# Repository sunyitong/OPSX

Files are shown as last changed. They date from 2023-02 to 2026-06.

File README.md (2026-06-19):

# OPSX-SX70

[中文](README.zh-CN.md) | English






OPSX-SX70 is an open-source replacement core board for the **Polaroid SX-70** instant camera, built around the Raspberry Pi RP2040. It provides a hackable, repair-friendly electronics platform while preserving the essential camera-control behavior of the original board.

## Highlights

- RP2040-based camera control board.
- Factory-ready Gerber files.
- Interactive HTML bill of materials.
- Schematic PDF for circuit inspection.
- MicroPython firmware for rapid iteration.
- Rust firmware workspace reserved for future high-performance control code.

## Repository Layout

| Path | Contents |
| --- | --- |
| [`bom/`](bom/) | Interactive HTML bill of materials for component lookup and placement. |
| [`code/micropython/`](code/micropython/) | Current firmware implementation for the RP2040 board. |
| [`code/rust/`](code/rust/) | Placeholder for future Rust firmware. |
| [`gerber/`](gerber/) | PCB production files and SMT position CSV. |
| [`schematic/`](schematic/) | One-page schematic PDF. |
| [`docs/`](docs/) | Fabrication, firmware, calibration, and safety notes. |

## Hardware

OPSX targets a thin two-layer PCB suitable for the physical constraints of the SX-70 body.

Recommended fabrication settings:

- **Layers:** 2 copper layers
- **PCB thickness:** 0.8 mm or less
- **Assembly:** review the interactive BOM before ordering or hand assembly
- **Files:** use the Gerber package under [`gerber/`](gerber/)

Read [`docs/fabrication.md`](docs/fabrication.md) before manufacturing.

## Firmware

The current firmware is written in MicroPython and lives in [`code/micropython/`](code/micropython/).

Core modules:

- `main.py`: camera-control loop, shutter/motor logic, exposure modes, distance display, and sensor integration.
- `ssd1306.py`: OLED display driver.
- `vl53l1x.py`: time-of-flight distance sensor driver.

Read [`docs/firmware.md`](docs/firmware.md) before flashing the board.

## Calibration and Safety

OPSX controls camera electromechanical parts including a shutter solenoid and motor. Incorrect calibration can damage the camera or board.

Before first use:

1. Read [`docs/safety.md`](docs/safety.md).
2. Inspect soldering and continuity.
3. Calibrate `SOLENOID_THRESHOLD` in `main.py`.
4. Test motor and sensor behavior outside the camera body where possible.
5. Reassemble only after confirming stable control behavior.

## Useful References

- Interactive BOM: [`bom/OPSX_bom.html`](bom/OPSX_bom.html)
- Schematic: [`schematic/OPSX_schematic.pdf`](schematic/OPSX_schematic.pdf)
- Gerbers: [`gerber/`](gerber/)
- KiCad source request: [issue #2](https://github.com/sunyitong/OPSX-SX70/issues/2)
- Latest release: <https://github.com/sunyitong/OPSX-SX70/releases/latest>
- SX-70 repair reference: <https://instantphotography.files.wordpress.com/2010/12/polaroid-sx-70-camera-repair-book.pdf>

## Roadmap

- Document complete assembly photographs.
- Package Gerber/BOM/schematic as GitHub Releases.
- Add firmware upload scripts.
- Add Rust firmware implementation.
- Add calibration logs for different SX-70 bodies.

## Author

Created by [Yitong Sun](https://github.com/sunyitong), a researcher and developer working across computational design, sensing systems, XR, and open hardware.

- Website: <https://www.yitongsun.com>
- Email: <hi@yitongsun.com>

## License

This project is released under the [GNU General Public License v3.0](LICENSE). Any distribution or modification based on this project should clearly attribute the source.

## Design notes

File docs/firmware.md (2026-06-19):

# Firmware Guide

The current OPSX firmware is implemented in MicroPython for RP2040.

## Files

- `code/micropython/main.py`: control logic and camera behavior
- `code/micropython/ssd1306.py`: OLED display driver
- `code/micropython/vl53l1x.py`: time-of-flight sensor driver

## Flashing Workflow

1. Install a MicroPython RP2040 firmware image on the board.
2. Copy the files in `code/micropython/` to the board filesystem.
3. Power-cycle the board.
4. Observe OLED output and sensor readings.
5. Calibrate `SOLENOID_THRESHOLD` before actuating the shutter inside a camera body.

## Important Constant

`SOLENOID_THRESHOLD` in `main.py` controls the hold duty cycle for the shutter solenoid. It should be tuned through self-test and should not be treated as universal across boards or camera bodies.

## Future Work

The `code/rust/` directory is reserved for a future Rust firmware implementation.

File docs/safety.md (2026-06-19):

# Safety Notes

OPSX is an experimental open-hardware project for camera repair, research, and modification.

## Mechanical Risk

The Polaroid SX-70 contains delicate mechanical assemblies. Disassembly and board replacement require care, patience, and appropriate tools.

Read the SX-70 repair reference before disassembly:

<https://instantphotography.files.wordpress.com/2010/12/polaroid-sx-70-camera-repair-book.pdf>

## Electrical Risk

- Inspect solder joints before applying power.
- Check for shorts on power rails.
- Do not actuate solenoids or motors without calibration.
- Watch for overheating during early tests.
- Disconnect power before reworking the board.

## Firmware Risk

Incorrect shutter or motor timings can damage mechanical parts. Calibrate gradually and document working values for each camera body.

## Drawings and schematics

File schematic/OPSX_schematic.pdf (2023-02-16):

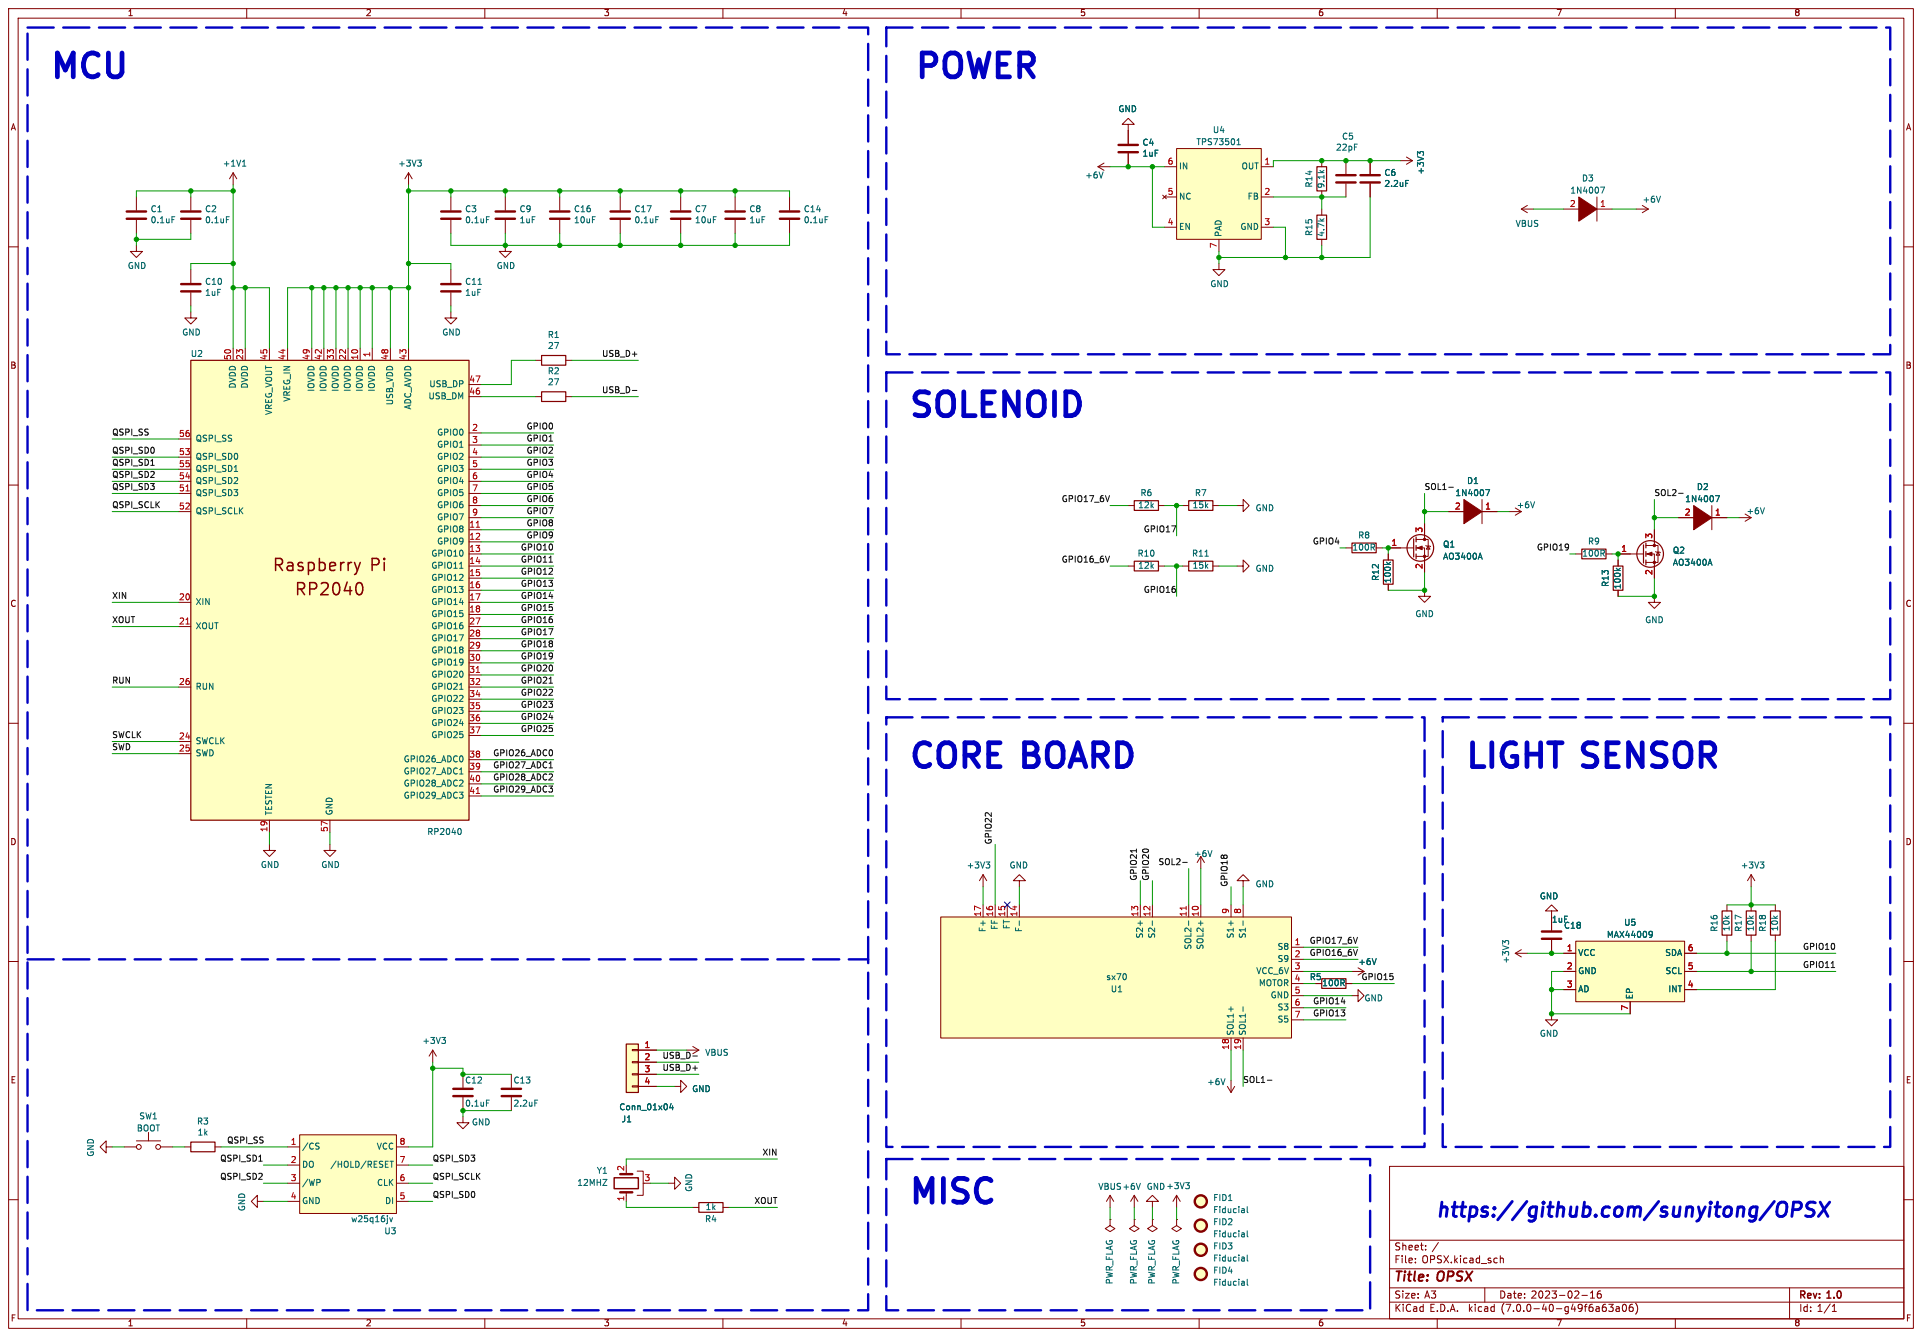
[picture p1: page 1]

1 IOVDD 10 GPIO8 11 GPIO9 12 GPIO10 13 GPIO11 14 GPIO12 15 GPIO13 16 GPIO14 17 GPIO15 18 TESTEN 19 GPIO0 2 XIN 20 XOUT 21 IOVDD 22 DVDD 23 SWCLK 24 SWD 25 RUN 26 GPIO16 27 GPIO17 28 GPIO18 29 GPIO1 3 GPIO19 30 GPIO20 31 GPIO21 32 IOVDD 33 GPIO22 34 GPIO23 35 GPIO24 36 GPIO25 37 GPIO26_ADC0 38 GPIO27_ADC1 39 GPIO2 4 GPIO28_ADC2 40 GPIO29_ADC3 41 IOVDD 42 ADC_AVDD 43 VREG_IN 44 VREG_VOUT 45 USB_DM 46 USB_DP 47 USB_VDD 48 IOVDD 49 GPIO3 5 DVDD 50 QSPI_SD3 51 QSPI_SCLK 52 QSPI_SD0 53 QSPI_SD2 54 QSPI_SD1 55 QSPI_SS 56 GND 57 GPIO4 6 GPIO5 7 GPIO6 8 GPIO7 9 U2 RP2040 GND

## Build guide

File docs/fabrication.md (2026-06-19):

# Fabrication Guide

OPSX is designed for the physical constraints of the Polaroid SX-70 body.

## Recommended PCB Settings

- 2 copper layers
- 0.8 mm thickness or less
- Standard solder mask
- Review edge cuts before ordering
- Review the SMT position CSV if using assembly service

## Production Files

Use the files under `gerber/`:

- copper: `OPSX-F_Cu.gbr`, `OPSX-B_Cu.gbr`
- solder mask: `OPSX-F_Mask.gbr`, `OPSX-B_Mask.gbr`
- paste: `OPSX-F_Paste.gbr`, `OPSX-B_Paste.gbr`
- silkscreen: `OPSX-F_Silkscreen.gbr`, `OPSX-B_Silkscreen.gbr`
- drills: `OPSX-PTH.drl`, `OPSX-NPTH.drl`
- board outline: `OPSX-Edge_Cuts.gbr`
- SMT placement: `OPSX-pos.csv`

## Pre-Order Checklist

- Confirm board thickness with the manufacturer.
- Open the Gerbers in an independent viewer.
- Check connector orientation and board outline.
- Review the interactive BOM in `bom/OPSX_bom.html`.
- Confirm that every component is available or has a tested substitute.

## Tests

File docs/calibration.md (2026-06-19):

# Calibration Notes

OPSX interacts with electromechanical parts whose behavior can vary across camera bodies. Treat the default values as a starting point, not as guaranteed production settings.

## Solenoid Threshold

`SOLENOID_THRESHOLD` is used to hold the shutter solenoid after the initial actuation pulse.

Recommended process:

1. Start with conservative values.
2. Test actuation outside the camera body if possible.
3. Check heat, current draw, and mechanical response.
4. Increase only when the shutter does not hold reliably.
5. Record the working value for the specific board and camera.

## Sensor Checks

- Confirm I2C communication before triggering mechanical actions.
- Confirm distance readings from the VL53L1X sensor.
- Confirm OLED output before final assembly.

## Exposure Modes

The MicroPython firmware contains exposure constants such as `ev7`, `ev8`, and `ev16`. If changing exposure behavior, document the mapping and test with real film only after bench verification.

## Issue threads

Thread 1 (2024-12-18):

控制板的文件

Armsinrius, 2024-12-18:
尊敬的Sun先生,
偶然看见您的开源项目OPSX，我个人觉得非常有意思．您在２０２３年２月１６日在小红书评论提到，将会修改控制器的部分方案后上传Github，然而我并未在此项目或您其他公开的项目中找到控制器的相关文件．如若允许，是否可以请求您上传控制器的方案．非常感谢您的工作给广大宝丽来爱好者带来的喜悦与便利．也非常感谢您无私的开源．
谨致问候

sunyitong, 2025-01-25:
你好，因为后来经过测试发现不同时期不同型号的SX-70机型的闪光灯插口的内置IC不同，所以目前的控制板并不能通用，如果需要通用则需要拆开机头将原装IC取出并替换一个柔性电路板进去。改造难度相对比较高，所以一直没有发布。

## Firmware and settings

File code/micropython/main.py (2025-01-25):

from machine import Pin, I2C, PWM
import time
from ssd1306 import SSD1306_I2C
from vl53l1x import VL53L1X
import framebuf

# Caution! This value is used to hold the shutter solenoid and should be modified by self-test.
SOLENOID_THRESHOLD = 20000


def shut(apture, f="1"):
    sht.duty_u16(65535)
    time.sleep_ms(18)
    sht.duty_u16(SOLENOID_THRESHOLD) 
    motor.value(1)
    while True:
        if s3.value() == 1:
            motor.value(0)
            break

    sht.duty_u16(0)
    if f == '0':
        gap=int(apture*0.3)
        time.sleep_ms(gap)
        fl.value(1)
        time.sleep_ms(gap)
        fl.value(0)
        time.sleep_ms(gap)
    elif f == '1':
        time.sleep_ms(apture)
    elif f == 'B':
        time.sleep_ms(15)
        while True:
            time.sleep_ms(3)
            if btn.value() == 1:
                break
    elif f == 'T':
        time.sleep(100)
        while True:
            time.sleep(3)
            if btn.value() == 0:
                break
        
    sht.duty_u16(65535)
    time.sleep_ms(20)
    sht.duty_u16(SOLENOID_THRESHOLD)
    motor.value(1)
    while True:
        if s5.value() == 0:
            motor.value(0)
            sht.duty_u16(0)
            break

def plug():
    a = plugI2c.readfrom_mem(32, 0x00, 2)
    one = "%8d" %int(bin(a[0])[2:])
    two = "%8d" %int(bin(a[1])[2:])
    one = one.replace(" ","0")
    return one+two

def showFrame():
    display.fill(0)
    display.fill_rect(0, 0, 128, 11, 1)
    display.vline(51, 0, 11, 0)
    display.vline(82, 0, 11, 0)
    
def backFunc():
    showFrame()
    fullp = plug()
    ec = fullp[2:6]
    sw = fullp[0:2]
    encoder()
    switch()
    dist()
    display.show()

# iso=1 for 600 paper =0 for 70 paper
def lux(iso=1):
    h = i2c.readfrom_mem(74, 0x03, 1)
    l = i2c.readfrom_mem(74, 0x04, 1)
    luxb = bin(((h[0] << 4) | l[0]) | 4096)
    expo = 8*int(luxb[3]) + 4*int(luxb[4]) + 2*int(luxb[5]) + int(luxb[6])
    manti = 128*int(luxb[7]) + 64*int(luxb[8]) + 32*int(luxb[9]) + 16*int(luxb[10]) + 8*int(luxb[11]) + 4*int(luxb[12]) + 2*int(luxb[13]) + int(luxb[14])
    lux = 2**expo * manti * 0.045
    if iso == 0:
        if 2.5<lux<=3.52:
            return ev75
        elif 3.52<lux<=4.99:
            return ev8
        elif 4.99<lux<=7.12:
            return ev85
        elif 7.12<lux<=10.13:
            return ev9
        elif 10.13<lux<=14.21:
            return ev95
        elif 14.21<lux<=19.79:
            return ev10
        elif 19.79<lux<=27.62:
            return ev105
        elif 27.62<lux<=39.01:
            return ev11
        elif 39.01<lux<=55.48:
            return ev115
        elif 55.48<lux<=78.07:
            return ev12
        elif 78.07<lux<=105.48:
            return ev125
        elif 105.48<lux<=150:
            return ev135
        elif 150<lux<=180:
            return ev145
        elif 180<lux<=200:
            return ev15
        elif 200<lux:
            return ev16
        else:
            return ev7
    else:
        if 0.3<lux<=0.5: 
            return ev75
        elif 0.5<lux<=0.9:
            return ev8
        elif 0.9<lux<=1.2:
            return ev85
        elif 1.2<lux<=1.74:
            return ev9
        elif 1.74<lux<=2.5:
            return ev95
        elif 2.5<lux<=3.52:
            return ev10
        elif 3.52<lux<=4.99:
            return ev105
        elif 4.99<lux<=7.12:
            return ev11
        elif 7.12<lux<=10.13:
            return ev115
        elif 10.13<lux<=14.21:
            return ev12
        elif 14.21<lux<=19.79:
            return ev125
        elif 19.79<lux<=27.62:
            return ev13
        elif 27.62<lux<=39.01:
            return ev135
        elif 39.01<lux<=55.48:
            return ev14
        elif 55.48<lux<=78.07:
            return ev145
        elif 78.07<lux<=105.48:
            return ev15
        elif 105.48<lux:
            return ev16
        else:
            return ev7

def encoder():
    if ec == EC_ZERO:
        display.text('AUTO', 10, 2, 0)
        return 'A'
    elif ec == EC_ONE:
        display.text('B', 23, 2, 0)
        return 'B'
    elif ec == EC_TWO:
        display.text('T', 23, 2, 0)
        return 'T'
    elif ec == EC_THREE:
        display.text('1/2', 15, 2, 0)
        return ev7
    elif ec == EC_FOUR:
        display.text('1/4', 15, 2, 0)
        return ev8
    elif ec == EC_FIVE:
        display.text('1/6', 15, 2, 0)
        return ev85
    elif ec == EC_SIX:
        display.text('1/8', 15, 2, 0)
        return ev9
    elif ec == EC_SEVEN:
        display.text('1/10', 10, 2, 0)
        return ev95
    elif ec == EC_EIGHT:
        display.text('1/15', 10, 2, 0)
        return ev10
    elif ec == EC_NINE:
        display.text('1/20', 10, 2, 0)
        return ev105
    elif ec == EC_A:
        display.text('1/30', 10, 2, 0)
        return ev11
    elif ec == EC_B:
        display.text('1/60', 10, 2, 0)
        return ev12
    elif ec == EC_C:
        display.text('1/125', 5, 2, 0)
        return ev13
    elif ec == EC_D:
        display.text('1/250', 5, 2, 0)
        return ev14
    elif ec == EC_E:
        display.text('1/500', 5, 2, 0)
        return ev15
    elif ec == EC_F:
        display.text('1/1000', 1, 2, 0)
        return ev16
    
def switch():
    if sw[0] == "1":
        display.text('600', 55, 2, 0)
    else:
        display.text('70', 59, 2, 0)
    if sw[1] == "1":
        display.text('OFF', 94, 2, 0)
    else:
        display.text('FLASH', 86, 2, 0)


def dist():
    display.text(str(round(tof.read()*0.001,2))+' m', 72, 23)

#基本定义
EC_ZERO = '1111'
EC_ONE = '0111'
EC_TWO = '1101'
EC_THREE = '0101'
EC_FOUR = '1110'
EC_FIVE = '0110'
EC_SIX = '1100'
EC_SEVEN = '0100'
EC_EIGHT = '1011'
EC_NINE = '0011'
EC_A = '1001'
EC_B = '0001'
EC_C = '1010'
EC_D = '0010'
EC_E = '1000'
EC_F = '0000'

ev7 = 600
ev75 = 440
ev8 = 280
ev85 =210
ev9 = 155
ev95 =120
ev10 = 97
ev105 = 70
ev11 = 48
ev115 = 40
ev12 = 33
ev125 = 29
ev13 = 25
ev135 = 23
ev14 = 21
ev145 = 20
ev15 = 19
ev16 = 18

back = "01"
front = "10"

#基本初始化
s8 = Pin(17, Pin.IN)
s9 = Pin(16, Pin.IN)
motor = Pin(15,Pin.OUT, value=0)
s3 = Pin(14, Pin.IN, Pin.PULL_UP)
s5 = Pin(13, Pin.IN, Pin.PULL_UP)
btn = Pin(18, Pin.IN, Pin.PULL_UP)
fl = Pin(22, Pin.OUT)
sht = PWM(Pin(4))
sht.freq(20000)
sht.duty_u16(0)
apt = Pin(19, Pin.OUT, value=0)
i2c = I2C(1, scl=Pin(11), sda=Pin(10))
plugI2c = I2C(0, scl=Pin(21), sda=Pin(20), freq=400000)
while True:
    plugscan = bool(plugI2c.scan())
    if plugscan == True:
        try:
            display = SSD1306_I2C(128, 32, plugI2c)
            display.contrast(0)
            tof = VL53L1X(plugI2c)
            fullp = plug()
            plugFlag = 1
            fb = fullp[6:8]
            func = "1"
            if fb == back:
                while True:
                    plugscan = bool(plugI2c.scan())
                    if plugscan == False:
                        break
                    else:
                        showFrame()
                        fullp = plug()
                        ec = fullp[2:6]
                        sw = fullp[0:2]
                        if sw[1] == "0":
                            display.text('FLASH', 86, 2, 0)
                            display.text('1/30', 10, 2, 0)
                            enc = 48
                            func = "0"
                        else:
                            display.text('OFF', 94, 2, 0)
                            enc = encoder()
                            func = "1"
                            if sw[0] == "0":
                                film = 0
                                display.text('70', 60, 2, 0)
                            else:
                                film = 1
                                display.text('600', 55, 2, 0)
                            if enc == 'A':
                                enc = lux(film)                 
                                display.text(str(enc)+' ms', 8, 23)
                            elif enc == 'B':
                                func = 'B'
                            elif enc == 'T':
                                func = 'T'
                        dist()
                        display.show()
                        for i in range(350):
                            if btn.value()==0:
                                shut(enc,func)
                            time.sleep_ms(1)
                                 
                        
            elif fb == front:          
                led_one = bytearray(b'\x00\x1c\x00\x00<\x00\x00|\x00\x00\xfc\x00\x01\xfc\x00\x07\xfc\x00\x0f\xfc\x00\x1f\xbc\x00\x1e<\x00\x1c<\x00\x10<\x00\x00\x1c\x00\x00\x1c\x00\x00<\x00\x00<\x00\x00<\x00\x00<\x00\x00\x1c\x00\x00<\x00\x00<\x00\x00>\x00\x00\x1c\x00\x00<\x00\x00<\x00\x00<\x00\x00<\x00\x00\x1c\x00\x00<\x00\x00\x1c\x00\x00<\x00')
                led_two = bytearray(b'\x03\xfc\x00\x0f\xff\x00\x1f\xff\x80>\x0f\xc0|\x03\xe0x\x01\xe0p\x01\xe0\xf0\x00\xe0p\x00\xf0\x00\x01\xe0\x00\x01\xe0\x00\x01\xe0\x00\x03\xe0\x00\x07\xc0\x00\x0f\x80\x00\x1f\x00\x00>\x00\x00~\x00\x00\xf8\x00\x01\xf0\x00\x03\xe0\x00\x0f\xc0\x00\x1f\x80\x00\x1f\x00\x00>\x00\x00|\x00\x00\xfa\x82\x80\xff\xff\xf0\xff\xff\xe0\xff\xff\xf0')
                led_three = bytearray(b'\x07\xfc\x00\x1f\xff\x00\x1f\xdf\x80>\x07\x80|\x07\xc0x\x03\xc0\xf0\x01\xc0p\x03\xe0\x00\x03\xc0\x00\x03\xc0\x00\x07\xc0\x00\x0f\x80\x00\xff\x00\x00\xfe\x00\x00\xff\x80\x01\x0f\xc0\x00\x03\xe0\x00\x01\xe0\x00\x01\xf0\x00\x00\xf0\x00\x00\xf0\x10\x00\xf0\xf0\x00\xf0\xf0\x01\xe0x\x01\xe0|\x03\xe0>\x07\xc0?\xbf\x80\x0f\xff\x00\x07\xfe\x00')
                led_four = bytearray(b'\x00\x07\x80\x00\x0f\x80\x00\x1f\x00\x00\x1f\x80\x00?\x80\x00\x7f\x80\x00\xff\x00\x00\xe7\x80\x01\xe7\x80\x03\xc7\x80\x03\x87\x00\x07\x87\x80\x0f\x07\x80\x0e\x0f\x80\x1e\x07\x00<\x07\x80x\x07\x80x\x07\x80\xf0\x07\x00\xfd\xbf\xe0\xff\xff\xf0\xff\xff\xf0\xff\xff\xf0\x00\x07\x80\x00\x07\x80\x00\x07\x00\x00\x07\x80\x00\x07\x00\x00\x07\x80\x00\x07\x80')
                led_five = bytearray(b'\x1f\xff\xc0\x1f\xff\xc0\x1f\xff\xc0?\xdb@<\x00\x00<\x00\x00<\x00\x008\x00\x008\x00\x00x\x00\x00{\xfc\x00\x7f\xff\x00\x7f\xff\x80\xfe\x0f\xc0x\x07\xc0\xf0\x03\xe0\x00\x01\xe0\x00\x01\xe0\x00\x00\xf0\x00\x01\xe0\x00\x01\xe0 \x01\xe0\xf0\x01\xe0\xf0\x01\xe0\xf0\x03\xc0|\x07\xc0~\x1f\x80?\xff\x00\x1f\xfe\x00\x03\xf8\x00')
                led_list = (led_five, led_four, led_three, led_two, led_one)
                while True:
                    showFrame()
                    fullp = plug()
                    ec = fullp[2:6]
                    sw = fullp[0:2]
                    if sw[1] == "0":
                        display.text('FLASH', 86, 2, 0)
                        display.text('1/30', 10, 2, 0)
                        enc = 48
                        func = "0"
                    else:
                        display.text('OFF', 94, 2, 0)
                        enc = encoder()
                        func = "1"
                        if sw[0] == "0":
                            film = 0
                            display.text('70', 60, 2, 0)
                        else:
                            film = 1
                            display.text('600', 55, 2, 0)
                        if enc == 'A':
                            enc = lux(film)                 
                            display.text(str(enc)+' ms', 8, 23)
                        elif enc == 'B':
                            func = 'B'
                        elif enc == 'T':
                            func = 'T'
                    display.text('SELFIE', 65, 23)
                    display.show()
                    for i in range(350):
                        if btn.value()==0:
                            display.contrast(255)
                            for i in range(5):
                                fb = framebuf.FrameBuffer(led_list[i], 20, 30, framebuf.MONO_HLSB)
                                display.fill(0)
                                display.blit(fb, 55, 0)
                                display.show()
                                time.sleep(0.8)
                                display.fill(1)
                                display.show()
                                time.sleep(0.2)
                            for i in range(5):
                                display.fill(1)
                                display.show()
                                time.sleep(0.13)
                                display.fill(0)
                                display.show()
                                time.sleep(0.13)                     
                            shut(enc,func)
                            display.contrast(0)
                        time.sleep_ms(1)
        except:
            pass
    else:
        enc = lux()
        for i in range(300):
            if btn.value()==0:
                shut(enc)

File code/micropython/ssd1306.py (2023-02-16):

from micropython import const
import framebuf

SET_CONTRAST = const(0x81)
SET_ENTIRE_ON = const(0xA4)
SET_NORM_INV = const(0xA6)
SET_DISP = const(0xAE)
SET_MEM_ADDR = const(0x20)
SET_COL_ADDR = const(0x21)
SET_PAGE_ADDR = const(0x22)
SET_DISP_START_LINE = const(0x40)
SET_SEG_REMAP = const(0xA0)
SET_MUX_RATIO = const(0xA8)
SET_COM_OUT_DIR = const(0xC0)
SET_DISP_OFFSET = const(0xD3)
SET_COM_PIN_CFG = const(0xDA)
SET_DISP_CLK_DIV = const(0xD5)
SET_PRECHARGE = const(0xD9)
SET_VCOM_DESEL = const(0xDB)
SET_CHARGE_PUMP = const(0x8D)

class SSD1306(framebuf.FrameBuffer):
    def __init__(self, width, height, external_vcc):
        self.width = width
        self.height = height
        self.external_vcc = external_vcc
        self.pages = self.height // 8
        self.buffer = bytearray(self.pages * self.width)
        super().__init__(self.buffer, self.width, self.height, framebuf.MONO_VLSB)
        self.init_display()

    def init_display(self):
        for cmd in (
            SET_DISP | 0x00,
            SET_MEM_ADDR,
            0x00,
            SET_DISP_START_LINE | 0x00,
            SET_SEG_REMAP | 0x01,
            SET_MUX_RATIO,
            self.height - 1,
            SET_COM_OUT_DIR | 0x08,
            SET_DISP_OFFSET,
            0x00,
            SET_COM_PIN_CFG,
            0x02 if self.width > 2 * self.height else 0x12,
            SET_DISP_CLK_DIV,
            0x80,
            SET_PRECHARGE,
            0x22 if self.external_vcc else 0xF1,
            SET_VCOM_DESEL,
            0x30,
            SET_CONTRAST,
            0xFF,
            SET_ENTIRE_ON,
            SET_NORM_INV,
            SET_CHARGE_PUMP,
            0x10 if self.external_vcc else 0x14,
            SET_DISP | 0x01,
        ):
            self.write_cmd(cmd)
        self.fill(0)
        self.show()

    def poweroff(self):
        self.write_cmd(SET_DISP | 0x00)

    def poweron(self):
        self.write_cmd(SET_DISP | 0x01)

    def contrast(self, contrast):
        self.write_cmd(SET_CONTRAST)
        self.write_cmd(contrast)

    def invert(self, invert):
        self.write_cmd(SET_NORM_INV | (invert & 1))

    def show(self):
        x0 = 0
        x1 = self.width - 1
        if self.width == 64:
            x0 += 32
            x1 += 32
        self.write_cmd(SET_COL_ADDR)
        self.write_cmd(x0)
        self.write_cmd(x1)
        self.write_cmd(SET_PAGE_ADDR)
        self.write_cmd(0)
        self.write_cmd(self.pages - 1)
        self.write_data(self.buffer)


class SSD1306_I2C(SSD1306):
    def __init__(self, width, height, i2c, addr=0x3C, external_vcc=False):
        self.i2c = i2c
        self.addr = addr
        self.temp = bytearray(2)
        self.write_list = [b"\x40", None]
        super().__init__(width, height, external_vcc)

    def write_cmd(self, cmd):
        self.temp[0] = 0x80
        self.temp[1] = cmd
        self.i2c.writeto(self.addr, self.temp)

    def write_data(self, buf):
        self.write_list[1] = buf
        self.i2c.writevto(self.addr, self.write_list)


class SSD1306_SPI(SSD1306):
    def __init__(self, width, height, spi, dc, res, cs, external_vcc=False):
        self.rate = 10 * 1024 * 1024
        dc.init(dc.OUT, value=0)
        res.init(res.OUT, value=0)
        cs.init(cs.OUT, value=1)
        self.spi = spi
        self.dc = dc
        self.res = res
        self.cs = cs
        import time

        self.res(1)
        time.sleep_ms(1)
        self.res(0)
        time.sleep_ms(10)
        self.res(1)
        super().__init__(width, height, external_vcc)

    def write_cmd(self, cmd):
        self.spi.init(baudrate=self.rate, polarity=0, phase=0)
        self.cs(1)
        self.dc(0)
        self.cs(0)
        self.spi.write(bytearray([cmd]))
        self.cs(1)

    def write_data(self, buf):
        self.spi.init(baudrate=self.rate, polarity=0, phase=0)
        self.cs(1)
        self.dc(1)
        self.cs(0)
        self.spi.write(buf)
        self.cs(1)

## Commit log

2023-02-16 Uploading schematic, gerber and bom files
    [OPSX-B_Cu.gbr, OPSX-B_Mask.gbr, OPSX-B_Paste.gbr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]
2023-02-16 Uploading SMT pos file
    [OPSX-pos.csv]
2026-06-19 Document KiCad source request
2026-06-19 Document KiCad source request in Chinese README

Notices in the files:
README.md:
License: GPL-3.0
